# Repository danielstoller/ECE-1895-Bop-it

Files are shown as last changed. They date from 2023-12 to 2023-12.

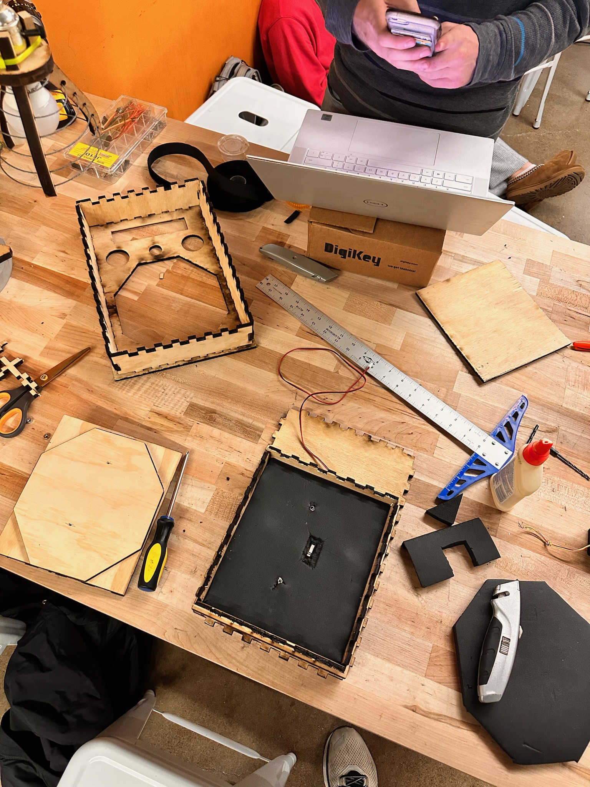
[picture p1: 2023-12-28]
Enclosure/pictures/enclosure_parts.JPG

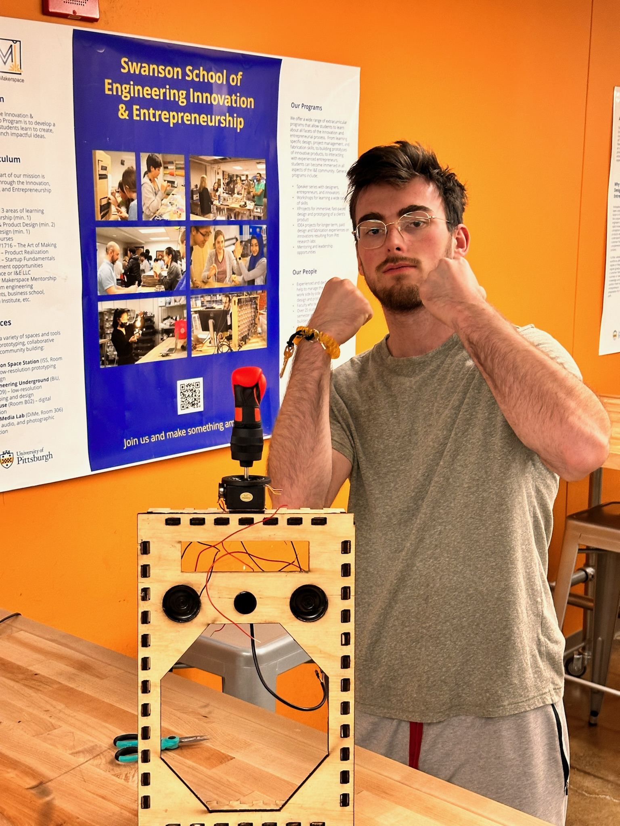
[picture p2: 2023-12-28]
Enclosure/pictures/IMG_3909.JPG

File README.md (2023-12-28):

# ECE 1895: Box It - The Boxing-Themed Twist on Bop It

## Objective

In our Junior Design class, my two teammates and I were tasked with creating a unique variation of the classic game Bop-It. The challenge included designing a game with three distinct actions, integrating both functional and hardware requirements. Box It offers a unique and physically engaging experience, turning a traditional punching bag into an interactive gaming device. Its combination of responsive sensors, intuitive actions, and immediate feedback makes it an exciting addition to both gaming and fitness routines. The primary objectives were to provide an engaging user experience, encourage physical activity, and incorporate responsive and intuitive decision making to help boxers sharpen their reaction time.

<br>

## Box It - The Implementation

Our twist on Bop It is called "Box It," a boxing-themed version of Bop It that is designed to be attached to a punching bag. The 13.5" x 8.5" laser printed enclosure houses various components including sensors, speakers, a display, a power source, and a PCB to connect them all together.

- **Actions:**
  1. **Punch It:**
     - Padded punching area with a limit switch detects hard punches.
  2. **Kick It:**
     - IR sensor on the side that detects kicks to the punching bag.
  3. **Dodge It:**
     - Proximity sensor in the center checks if the user successfully dodged.

- **Enclosure Features:**
  - LED matrix display with animations for visual cues.
  - Two speakers for audible commands.
  - Proximity sensor for responsive precise detection.
  - IR sensor for radial, inclusive detection
  - Limit switch for registering powerful punches.

- **Scoring and Feedback:**
  - Successful actions earn points, challenging users with decreasing time intervals.
  - Visual cues indicate success or failure, and the game ends after 99 successful attempts.

## Youtube Demonstration:
Watch the Video (https://youtu.be/TcJYKmGF-bU)

<br>

## Design Requirements

### Functional / Software Requirements

- **Power and Activation:**
  - The user can power the device on or off.
  - Upon activation, a button starts the game.

- **Game Commands:**
  - The device emits distinct, audible sounds specifying one of three commands.
  - The user must respond to the command with the corresponding action.

- **Scoring and Difficulty:**
  - Successful responses earn the user points.
  - After each successful attempt, the device issues a new command with a reduced time interval.
  - The game ends after 99 successful attempts, and the user is notified of their score.

- **Visual Cues:**
  - Visual cues indicate success or failure, providing immediate feedback to the user.

### Hardware Requirements

- **Power Source:**
  - The device is portable and battery-powered.

- **Enclosure:**
  - The device is enclosed with only inputs and outputs visible.
  - Compact and portable design for ease of use.

- **User Inputs:**
  - User-controlled inputs for powering the device and starting a new game.
  - Three tactile/sensory inputs for user responses.

- **Device Outputs:**
  - Three audible outputs for command specification.
  - Visual confirmation for successful and unsuccessful attempts.
  - Score notification at the end of each round.
 
<br>

## Responsibilities
- **Myself:**
    - Enclosure design, modeling, printing and assembly
    - LED Matrix animations
- **Tyler:**
    - PCB design and assembly
    - Component integration
- **Keegan:**
    - Game design and software

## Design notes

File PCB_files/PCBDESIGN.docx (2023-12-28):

Group Theta

Tyler Wiseman

Keegan Borig

Daniel Stoller

BopIt PCB

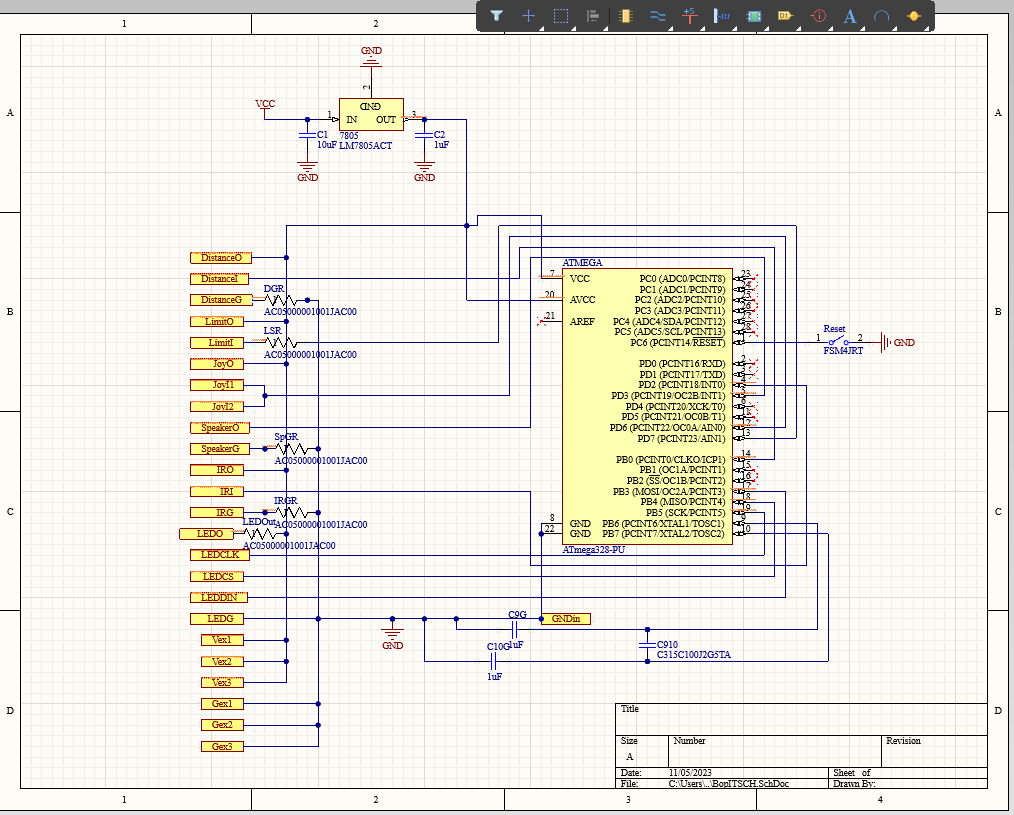
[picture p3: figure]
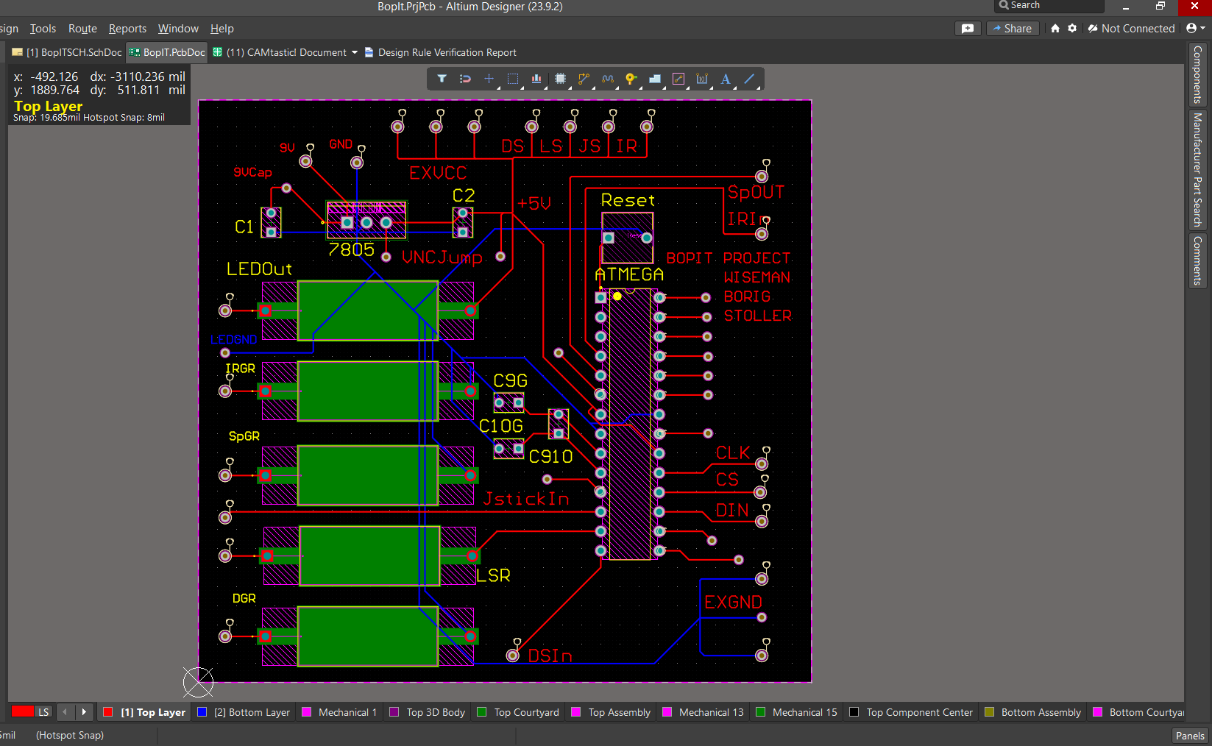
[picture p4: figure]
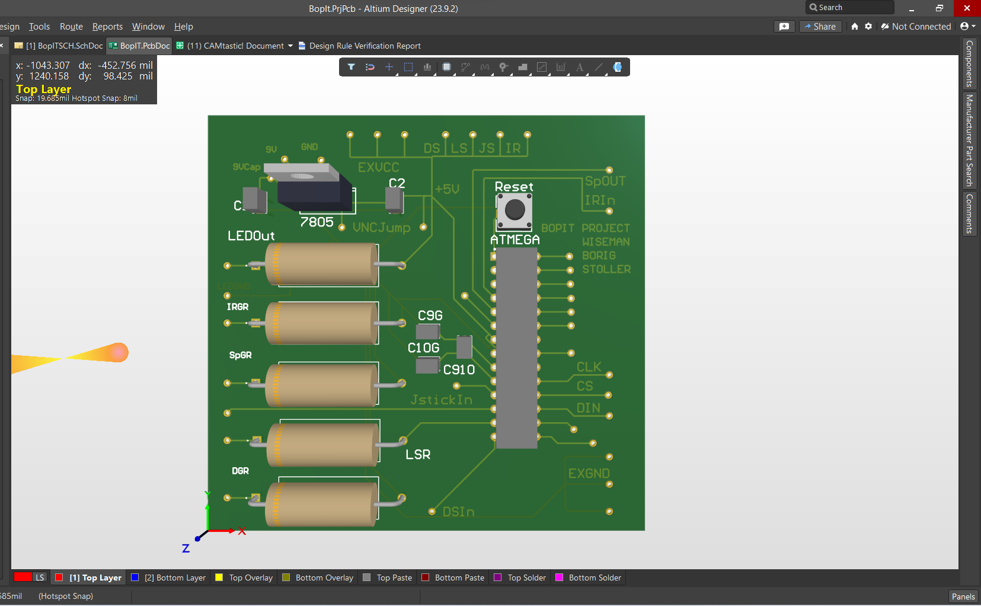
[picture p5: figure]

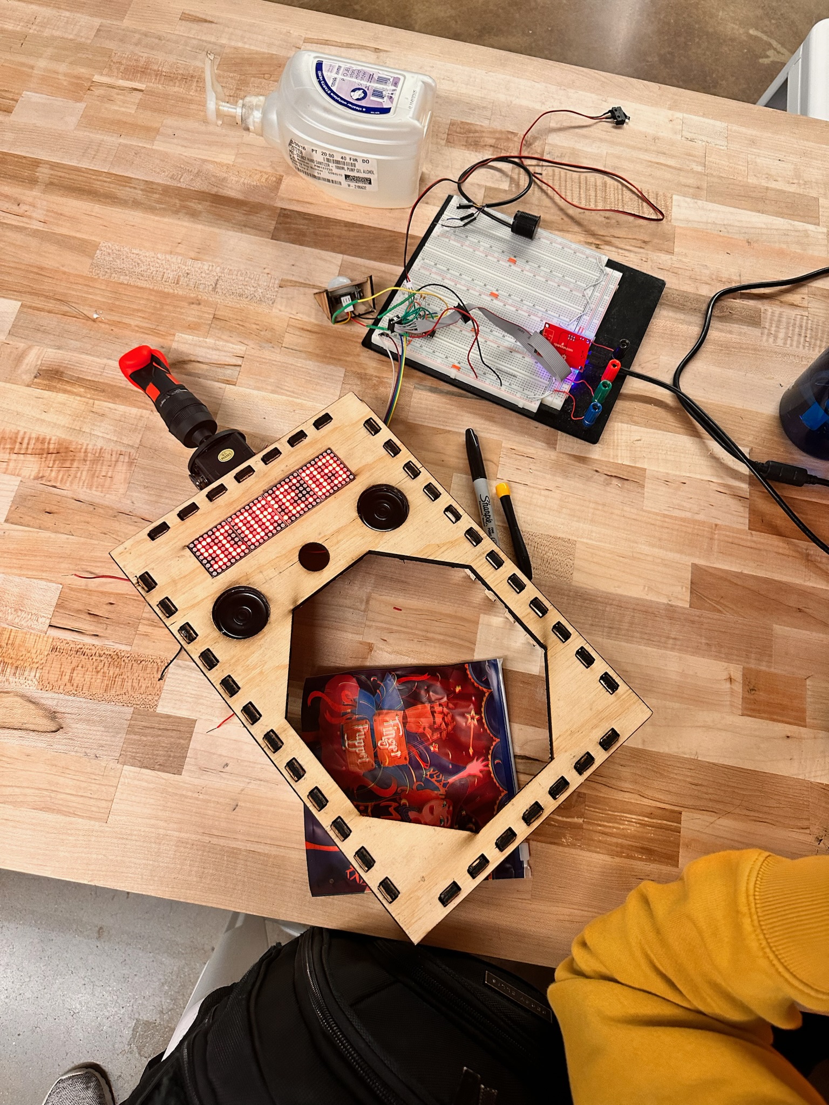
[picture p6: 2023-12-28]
Enclosure/pictures/enclosure_breadboard.JPG

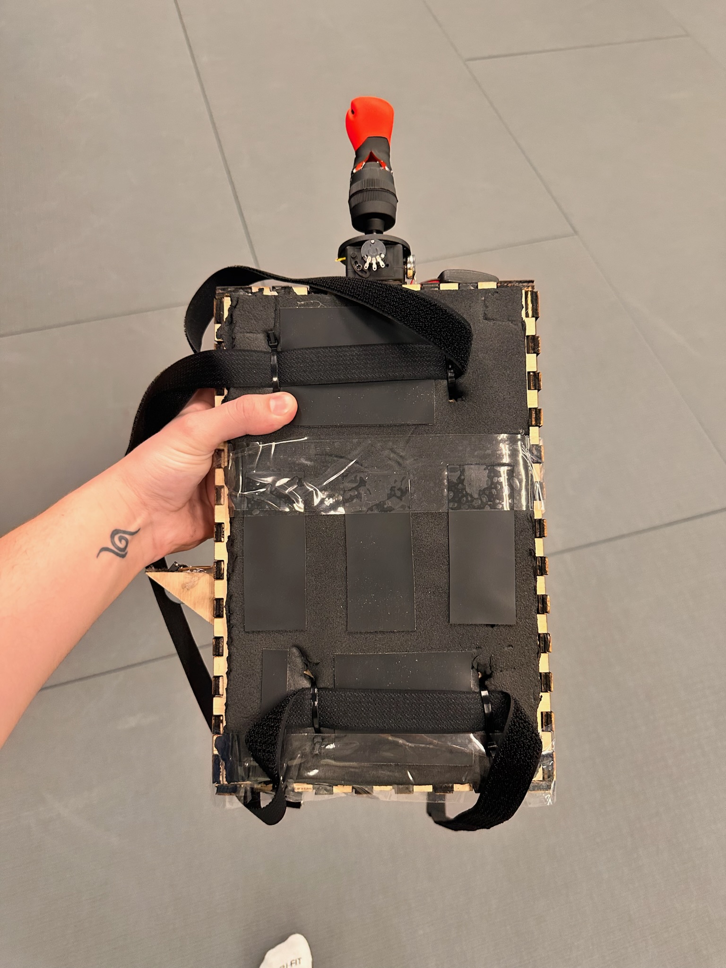
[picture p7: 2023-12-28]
Enclosure/pictures/enclosure_back.JPG

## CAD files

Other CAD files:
Enclosure/Enclosure Model v2.f3d

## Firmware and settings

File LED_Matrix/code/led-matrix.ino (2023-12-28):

#include <LedControl.h>

#include <LedControl.h>

#include <LedControl.h>

#include "LedControl.h"

//CLK is 13
//CS is 12
//DIN is 11

LedControl lc=LedControl(11,13,12,4);  // Pins: DIN,CLK,CS, # of Display connected

unsigned long delayTime=200;  // Delay between Frames


//lc.setRow(1, 0, B11100000);




void clear(){
  for(int i=0; i<4; i++)
    lc.clearDisplay(i);
}


void display(byte word[], int start, int size){
  for(int i=start; i<size; i++){
    if(i<0)
      lc.setColumn(3-i/8, i%8, word[i+start]);
  }
}


////////LOADING UP SCREEN//////////
byte leftPunch[] = 
{
  B01111100,
  B01000100,
  B01111110,
  B01111010,
  B01111110,
  B01111000,
  B01111000,
  B00111000
};



//Punches left glove across the screen
//i is the tip of the glove
//j is the bytes of the punching glove
void loadingScreen(){
  clear();
  for(int i=0; i<32; i++){
    for(int j=0; j<8; j++){
      if(j <= i)
        lc.setColumn(3-(i-j)/8, (i-j)%8, leftPunch[j]);  
    }
    delay(50);
  }
  
  /*
  delay(1000);
  clear();
  */
}


/////////START SCREEN/////////

byte start[] =
{
  B01110010,
  B01010010,
  B01011110,
  B00100000,
  B01111110,
  B00100000,
  B00000000,
  B00011110,

  B00010100,
  B00011110,
  B00000000,
  B00011110,
  B00010000,
  B00100000,
  B01111110,
  B00100000
};


//This puts the word start at the center of the screen
void showStart() {
  for (int i = 0; i < 16; i++)
  {
    lc.setColumn(2-i/8, i%8, start[i]);
  }
}


//Extended punch on both sides
void punchIn()
{
  for (int i = 0; i < 8; i++)
  {
    lc.setColumn(3, 7-i, leftPunch[i]);
    lc.setColumn(0, i, leftPunch[i]);
  }

  delay(2000);
}

//Retracted punch on both sides
void punchOut()
{
  lc.setColumn(3, 7, B00000000);
  lc.setColumn(0, 0, B00000000);
  for (int i = 0; i < 7; i++)
  {
    lc.setColumn(3, 6-i, leftPunch[i]);
    lc.setColumn(0, 1+i, leftPunch[i]);
  }
  delay(2000);
}

//This punches in and out once
void showPunch(){
  punchIn();
  punchOut();
}
  

//Displays start, then punches in and out once
//For overall code, startScreen(), while(joystick==0) showPunch();
void startScreen()
{
  clear();
  showStart();
  showPunch();
}


////////DODGE/////////

byte dodge[] = 
{
  //D, half of O
  B01111110,
  B01000010,
  B01000010,
  B00100100,
  B00011000,
  B00000000,
  B01111110,
  B01000010,

  //half of O, D
  B01000010,
  B01111110,
  B00000000,
  B01111110,
  B01000010,
  B01000010,
  B00100100,
  B00011000,

  //G, most of E
  B00000000,
  B01111110,
  B01000010,
  B01001010,
  B01001110,
  B00000000,
  B01111110,
  B01010010,

  //byte of E, slipstream
  B01010010,



  B00000000,
  B00010010,
  B00100100,
  B01001000,
  B01001000,
  B00100100,
  B00010010,

  //slipstream
  B00010010,
  B00100100,
  B01001000,
  B01001000,
  B00100100,
  B00010010,
  B00010010,
  B00100100,

  //slipstream
  B01001000,
  B01001000,
  B00100100,
  B00010010,
  B00010010,
  B00100100,
  B01001000,
  B01001000,
  B00100100,
  B00010010,

  //slipstream
  B00010010,
  B00100100,
  B01001000,
  B01001000,
  B00100100,
  B00010010,
  B00010010,
  B00100100
};



void showDodge(){
  //Will display 4 from the left and 5 from the right
  
  //**
  lc.setColumn(3, 0, B00000000);
  lc.setColumn(3, 1, B01000100);
  lc.setColumn(3, 2, B10101010);
  //**
  
  for(int i=4; i<30; i++){
    lc.setColumn(3-i/8, i%8, dodge[i-4]);
  }

  //**
  lc.setColumn(0, 5, B00000000);
  lc.setColumn(0, 6, B01000100);
  lc.setColumn(0, 7, B10101010);
  //**
}

//Arrows go in and out once
void dodgeArrows(){
  for(int i=1; i<3; i++){
    if(i%2){  //Extended
      lc.setColumn(3, 0, B01000010);
      lc.setColumn(3, 1, B10100101);
      lc.setColumn(3, 2, B00000000);
      lc.setColumn(0, 5, B01000010);
      lc.setColumn(0, 6, B10100101);
      lc.setColumn(0, 7, B00000000);
      delay(600);
    }
    else{   //Retracted
      lc.setColumn(3, 0, B00000000);
      lc.setColumn(3, 1, B01000010);
      lc.setColumn(3, 2, B10100101);
      lc.setColumn(0, 5, B00000000);
      lc.setColumn(0, 6, B01000010);
      lc.setColumn(0, 7, B10100101);
      delay(300);
    }
  }
}

//Will show the word dodge and arrows will go in and out n times
void dodgeScreen(int n){
  clear();
  showDodge();
  for(int i=0; i<n; i++){
    dodgeArrows();
  }
}


/////////PUNCH////////

byte punch[] = 
{
  //P and U
  B01111110,
  B01010000,
  B01110000,
  B00000000,
  B01111110,
  B00000010,
  B01111110,
  B00000000,

  //N and C
  B01111110,
  B00100000,
  B00010000,
  B01111110,
  B00000000,
  B01111110,
  B01000010,
  B01000010,

  //H
  B00000000,
  B01111110,
  B00010000,
  B01111110
};

void showPunch(){
  for(int i=6; i<26; i++){
    lc.setColumn(3-i/8, i%8, punch[i-6]);
  }
}

//The speed can be a number between 1 and 5
//1 is the fastest, 5 is the slowest
void explosion(int speed){
  for(int i=0; i<7; i++){
    if(i%7 == 0){  //Extended
      lc.setColumn(3, 0, B00000000);
      lc.setColumn(3, 1, B00000000);
      lc.setColumn(3, 2, B00000000);
      lc.setColumn(3, 3, B00000000);
      lc.setColumn(3, 4, B00011000);
      lc.setColumn(0, 3, B00011000);
      lc.setColumn(0, 4, B00000000);
      lc.setColumn(0, 5, B00000000);
      lc.setColumn(0, 6, B00000000);
      lc.setColumn(0, 7, B00000000);
      delay(speed*20);
    }
    else if(i%7 == 1){   //Retracted
      lc.setColumn(3, 3, B00011000);
      lc.setColumn(3, 4, B00100100);
      lc.setColumn(0, 4, B00011000);
      lc.setColumn(0, 3, B00100100);
      delay(speed*20);
    }
    else if(i%7 == 2){   //Retracted
      lc.setColumn(3, 2, B00011000);
      lc.setColumn(3, 3, B00100100);
      lc.setColumn(3, 4, B01000010);
      lc.setColumn(0, 5, B00011000);
      lc.setColumn(0, 4, B00100100);
      lc.setColumn(0, 3, B01000010);
      delay(speed*20);
    }
    else if(i%7 == 3){   //Retracted
      lc.setColumn(3, 1, B00011000);
      lc.setColumn(3, 2, B00100100);
      lc.setColumn(3, 3, B01000010);
      lc.setColumn(3, 4, B10000001);
      lc.setColumn(0, 6, B00011000);
      lc.setColumn(0, 5, B00100100);
      lc.setColumn(0, 4, B01000010);
      lc.setColumn(0, 3, B10000001);
      delay(speed*20);
    }
    else if(i%7 == 4){   //Retracted
      lc.setColumn(3, 0, B00011000);
      lc.setColumn(3, 1, B00100100);
      lc.setColumn(3, 2, B01000010);
      lc.setColumn(3, 3, B10000001);
      lc.setColumn(3, 4, B00000000);
      lc.setColumn(0, 7, B00011000);
      lc.setColumn(0, 6, B00100100);
      lc.setColumn(0, 5, B01000010);
      lc.setColumn(0, 4, B10000001);
      lc.setColumn(0, 3, B00000000);
      delay(speed*20);
    }
    else if(i%7 == 5){   //Retracted
      lc.setColumn(3, 0, B00100100);
      lc.setColumn(3, 1, B01000010);
      lc.setColumn(3, 2, B10000001);
      lc.setColumn(3, 3, B00000000);
      lc.setColumn(0, 7, B00100100);
      lc.setColumn(0, 6, B01000010);
      lc.setColumn(0, 5, B10000001);
      lc.setColumn(0, 4, B00000000);
      delay(speed*20);
    }
    else if(i%7 == 6){   //Retracted
      lc.setColumn(3, 0, B01000010);
      lc.setColumn(3, 1, B10000001);
      lc.setColumn(3, 2, B00000000);
      lc.setColumn(0, 7, B01000010);
      lc.setColumn(0, 6, B10000001);
      lc.setColumn(0, 5, B00000000);
      delay(speed*40);
    }
  }
}


void punchScreen(int n, int speed){
  clear();
  showPunch();
  for(int i=0; i<n; i++)
    explosion(speed);
}


////////KICK/////////

byte kick[] = 
{
  //K and I
  B01111110,
  B00010000,
  B00101000,
  B01000110,
  B00000000,
  B01000010,
  B01111110,
  B01000010,

  //C and most of K
  B00000000,
  B01111110,
  B01000010,
  B01000010,
  B00000000,
  B01111110,
  B00010000,
  B00101000,

  B01000110
};


void showKick(){
  for(int i=1; i<18; i++){
    lc.setColumn(3-i/8, i%8, kick[i-1]);
  }
}

byte man[] = 
{
  B11101001,
  B11111110,
  B11101001
};

byte flyingMan1[] = 
{
  B11101001,
  B11111110,
  B11101010,
  B00000100
};

byte flyingMan2[] = 
{
  B00000100,
  B11101001,
  B11111110,
  B11101010,
  B00000100,
  B00001000,
  B00010000
};


//Speed can be between 1 and 5 with 5 being the slowest
void flyingKick(int speed){
  
  //Standing man
  for(int i=19; i<22; i++){
    lc.setColumn(3-i/8, i%8, man[i-19]);
  }
  delay(120+30*speed);

  //Leg up
  //Clear previous line
  lc.setColumn(1, 3, B00000000);
  for(int i=20; i<24; i++){
    lc.setColumn(3-i/8, i%8, flyingMan1[i-20]);
  }

  delay(100+30*speed);

  //Flying kick
  for(int i=0; i<5; i++){
    //Clear previous line
    lc.setColumn(3-(i+20)/8, (i+20)%8, B00000000);
    for(int j=21; j<27; j++){
      lc.setColumn(3-(j+i)/8, (j+i)%8, flyingMan2[j-21]);
    }
    delay(60+30*speed);
  }

  //Leg up
  lc.setColumn(0, 1, B00000000);
  lc.setColumn(0, 2, B00000000);
  for(int i=27; i<30; i++){
    lc.setColumn(3-i/8, i%8, flyingMan1[i-27]);
  }
  lc.setColumn(0, 6, B00000000);
  delay(100+30*speed);

  //Standing man
  lc.setColumn(0, 2, B00000000);
  lc.setColumn(0, 3, B0000000);
  for(int i=28; i<31; i++){
    lc.setColumn(3-i/8, i%8, man[i-28]);
  }

  delay(170+30*speed);
  
  //Clear man
  for(int i=27; i<31; i++){
    lc.setColumn(3-i/8, i%8, B00000000);
  }
  

}

void kickScreen(){
  clear();
  showKick();
  flyingKick();
}


/////////SCORE////////

byte score[]{
  //S and C
  B00000000,
  B01110010,
  B01010010,
  B01011110,
  B00000000,
  B01111110,
  B01000010,
  B01000010,

  //O and most of R
  B00000000,
  B01111110,
  B01000010,
  B01111110,
  B00000000,
  B01111110,
  B01011000,
  B01010100,

  //little bit of R, E and :
  B01110010,
  B00000000,
  B01111110,
  B01010010,
  B01010010,
  B00000000,
  B01000010,
  B00000000
};

byte zero[]{
  B01111110,
  B01000010,
  B01111110
};

byte one[]{
  B00100010,
  B01111110,
  B00000010
};


byte two[]{
  B01011110,
  B01010010,
  B01110010
};


byte three[]{
  B01010010,
  B01010010,
  B01111110
};


byte four[]{
  B01110000,
  B00010000,
  B01111110
};


byte five[]{
  B01110010,
  B01010010,
  B01011110
};


byte six[]{
  B01111110,
  B00001010,
  B00001110
};


byte seven[]{
  B01000000,
  B01000000,
  B01111110
};


byte eight[]{
  B01111110,
  B01010010,
  B01111110
};


byte nine[]{
  B01110000,
  B01010000,
  B01111110
};


void showScore(){
  for(int i=0; i<24; i++){
    lc.setColumn(3-i/8, i%8, score[i]);
  }
}


void showTens(int num){
  if(num > 99)
    return;

  if(num/10 == 0){
    for(int i=0; i<3; i++)
      lc.setColumn(0, i, zero[i]);
  }
  else if(num/10 == 1){
    for(int i=0; i<3; i++)
      lc.setColumn(0, i, one[i]);
  }
  else if(num/10 == 2){
    for(int i=0; i<3; i++)
      lc.setColumn(0, i, two[i]);
  }
  else if(num/10 == 3){
    for(int i=0; i<3; i++)
      lc.setColumn(0, i, three[i]);
  }
  else if(num/10 == 4){
    for(int i=0; i<3; i++)
      lc.setColumn(0, i, four[i]);
  }
  else if(num/10 == 5){
    for(int i=0; i<3; i++)
      lc.setColumn(0, i, five[i]);
  }
  else if(num/10 == 6){
    for(int i=0; i<3; i++)
      lc.setColumn(0, i, six[i]);
  }
  else if(num/10 == 7){
    for(int i=0; i<3; i++)
      lc.setColumn(0, i, seven[i]);
  }
  else if(num/10 == 8){
    for(int i=0; i<3; i++)
      lc.setColumn(0, i, eight[i]);
  }
  else{
    for(int i=0; i<3; i++)
      lc.setColumn(0, i, nine[i]);
  }
}

void showOnes(int num){
  if(num > 99)
    return;

  if(num%10 == 0){
    for(int i=0; i<3; i++)
      lc.setColumn(0, i+4, zero[i]);
  }
  else if(num%10 == 1){
    for(int i=0; i<3; i++)
      lc.setColumn(0, i+4, one[i]);
  }
  else if(num%10 == 2){
    for(int i=0; i<3; i++)
      lc.setColumn(0, i+4, two[i]);
  }
  else if(num%10 == 3){
    for(int i=0; i<3; i++)
      lc.setColumn(0, i+4, three[i]);
  }
  else if(num%10 == 4){
    for(int i=0; i<3; i++)
      lc.setColumn(0, i+4, four[i]);
  }
  else if(num%10 == 5){
    for(int i=0; i<3; i++)
      lc.setColumn(0, i+4, five[i]);
  }
  else if(num%10 == 6){
    for(int i=0; i<3; i++)
      lc.setColumn(0, i+4, six[i]);
  }
  else if(num%10 == 7){
    for(int i=0; i<3; i++)
      lc.setColumn(0, i+4, seven[i]);
  }
  else if(num%10 == 8){
    for(int i=0; i<3; i++)
      lc.setColumn(0, i+4, eight[i]);
  }
  else{
    for(int i=0; i<3; i++)
      lc.setColumn(0, i+4, nine[i]);
  }
}

void scoreScreen(int score){
  clear();
  showScore();
  showTens(score);
  showOnes(score);
}


////LOSE SCREEN////

byte youLose[] =
{
  B01000000,
  B00100000,
  B00011110,
  B00100000,
  B01000000,
  B00111100,
  B01000010,
  B01000010,

  B00111100,
  B00000000,
  B01111110,
  B00000010,
  B01111110,
  B00000000,
  B00000000,
  B00000000,

  B01111110,
  B00000010,
  B00000010,
  B00000000,
  B00111100,
  B01000010,
  B01000010,
  B00111100,

  B00000000,
  B01110010,
  B01010010,
  B01011110,
  B00000000,
  B01111110,
  B01010010,
  B01000010,
};

byte pathetic[] =
{
  //P and A
  B01111110,
  B01010000,
  B01110000,
  B00000000,
  B01111110,
  B01001000,
  B01111110,
  B00000000,
  
  //T and H
  B01000000,
  B01111110,
  B01000000,
  B00000000,
  B01111110,
  B00010000,
  B01111110,
  B00000000,
  
  //E, T and part of I
  B01111110,
  B01010010,
  B00000000,
  B01000000,
  B01111110,
  B01000000,
  B00000000,
  B01000010,
  
  //Most of I, C, and period
  B01111110,
  B01000010,
  B00000000,
  B01111110,
  B01000010,
  B01000010,
  B00000000,
  B00000010,
};

byte laughable[] =
{
  //L, A, and part of U
  B01111110,
  B00000010,
  B00000000,
  B01111110,
  B01010000,
  B01111110,
  B00000000,
  B01111110,
  
  //Most of U, G, and part of H
  B00000010,
  B01111110,
  B00000000,
  B01111110,
  B01000010,
  B01001110,
  B00000000,
  B01111110,

  //Most of H, A, and part of B
  B00010000,
  B01111110,
  B00000000,
  B01111110,
  B01010000,
  B01111110,
  B00000000,
  B01111110,

  //Most of B, L, and E
  B01010010,
  B00101100,
  B00000000,
  B01111110,
  B00000010,
  B00000000,
  B01111110,
  B01010010
};

byte abysmal[] =
{
  //A and B
  B01111110,
  B01010000,
  B01111110,
  B00000000,
  B01111110,
  B01010010,
  B01010010,
  B00101100,
  
  //Y and part of S
  B00000000,
  B01000000,
  B00100000,
  B00011110,
  B00100000,
  B01000000,
  B00000000,
  B01110010,
  
  //Most of S and M
  B01010010,
  B01011110,
  B00000000,
  B01111110,
  B00100000,
  B00010000,
  B00100000,
  B01111110,
  
  //A and L
  B00000000,
  B01111110,
  B01010000,
  B01111110,
  B00000000,
  B01111110,
  B00000010,
  B00000010
};

void showBoo(){
  int randNum = random(0,3);
  for(int i=0; i<32; i++){
    if(randNum == 1)
      lc.setColumn(3-i/8, i%8, pathetic[i]);
    else if(randNum == 2)
      lc.setColumn(3-i/8, i%8, abysmal[i]);
    else
      lc.setColumn(3-i/8, i%8, laughable[i]);
  }
}

void showLose(){
  for(int i=0; i<32; i++){
    lc.setColumn(3-i/8, i%8, youLose[i]);
  }
}

void glitch(){
  for(int count = 0; count < 5; count++){
    for(int row=0; row<8; row++){
      for(int addr = 0; addr<4; addr++)
        for(int pixel=0; pixel<8; pixel++){
          int randNum = random(0,4);
          lc.setLed(addr, row, pixel, randNum);
        }
    }
  }
}


void loseScreen(){

  clear();

  //Transition Screen//
  glitch();
  
  showBoo();
  delay(1500);
  showLose();
  delay(1500);
  clear();
}



////////WIN////////


byte sublime[] = 
{
  //S and U
  B00000000,
  B01110010,
  B01010010,
  B01011110,
  B00000000,
  B01111110,
  B00000010,
  B01111110,
  
  //B and most of L
  B00000000,
  B01111110,
  B01010010,
  B01010010,
  B00101100,
  B00000000,
  B01111110,
  B00000010,
  
  //Part of L, I, and half of M
  B00000010,
  B00000000,
  B01000010,
  B01111110,
  B01000010,
  B00000000,
  B01111110,
  B00100000,
  
  //Half of M and E
  B00010000,
  B00100000,
  B01111110,
  B00000000,
  B01111110,
  B01010010,
  B01010010,
  B00000000
};

byte hooray[] =
{
  //H and O
  B00000000,
  B01111110,
  B00010000,
  B01111110,
  B00000000,
  B01111110,
  B01000010,
  B01111110,

  //O and most of R
  B00000000,
  B01111110,
  B01000010,
  B01111110,
  B00000000,
  B01111110,
  B01011000,
  B01010100,
  
  //Bit of R, A, and half of Y
  B01110010,
  B00000000,
  B01111110,
  B01010000,
  B01111110,
  B00000000,
  B01000000,
  B00100000,
  
  //Half of Y and !
  B00011110,
  B00100000,
  B01000000,
  B00000000,
  B00000000,
  B01111010,
  B00000000,
  B00000000,
};

byte cheeky[] =
{
  //C and H
  B00000000,
  B01111110,
  B01000010,
  B01000010,
  B00000000,
  B01111110,
  B00010000,
  B01111110,

  //Both E's
  B00000000,
  B01111110,
  B01010010,
  B01010010,
  B00000000,
  B01111110,
  B01010010,
  B01010010,
  
  //K and half of Y
  B00000000,
  B01111110,
  B00010000,
  B00101000,
  B01000110,
  B00000000,
  B01000000,
  B00100000,
  
  //Half of Y and !
  B00011110,
  B00100000,
  B01000000,
  B00000000,
  B00000000,
  B01111010,
  B00000000,
  B00000000,
};

byte blimey[] =
{
  //B and most of L
  B00000000,
  B01111110,
  B01010010,
  B01010010,
  B00101100,
  B00000000,
  B01111110,
  B00000010,

  //part of L, I, and half of M
  B00000010,
  B00000000,
  B01000010,
  B01111110,
  B01000010,
  B00000000,
  B01111110,
  B00100000,

  //Half of M and E
  B00010000,
  B00100000,
  B01111110,
  B00000000,
  B01111110,
  B01010010,
  B01010010,
  B00000000,
  
  //Y and !
  B01000000,
  B00100000,
  B00011110,
  B00100000,
  B01000000,
  B00000000,
  B01111010,
  B00000000,
};

byte youWin[] =
{
  //Y and part of O
  B00000000,
  B01000000,
  B00100000,
  B00011110,
  B00100000,
  B01000000,
  B00000000,
  B01111110,

  //Most of O and U
  B01000010,
  B01111110,
  B00000000,
  B01111110,
  B00000010,
  B01111110,
  B00000000,
  B00000000,
  
  //W and part of I
  B00000000,
  B01111110,
  B00000010,
  B00011110,
  B00000010,
  B01111110,
  B00000000,
  B01000010,
  
  //Most of I and N
  B01111110,
  B01000010,
  B00000000,
  B01111110,
  B00100000,
  B00010000,
  B01111110,
  B00000000
};

void showCongrats(){
  int randNum = random(0,4);
  for(int i=0; i<32; i++){
    if(randNum == 0)
      lc.setColumn(3-i/8, i%8, sublime[i]);
    else if(randNum == 1)
      lc.setColumn(3-i/8, i%8, hooray[i]);
    else if (randNum == 2)
      lc.setColumn(3-i/8, i%8, cheeky[i]);
    else
      lc.setColumn(3-i/8, i%8, blimey[i]);
  }
}

void showWin(){
  for(int i=0; i<32; i++){
    lc.setColumn(3-i/8, i%8, youWin[i]);
  }
}

void winScreen(){
  
  clear();
  //Transition screeen
  glitch();
  
  showCongrats();

  delay(1000);

  clear();
  showWin();

  delay(1000);

  clear();
}


void setup()
{
  lc.shutdown(0,false);  // Wake up displays
  lc.shutdown(1,false);
  lc.shutdown(2,false);
  lc.shutdown(3,false);
  lc.setIntensity(0,5);  // Set intensity levels
  lc.setIntensity(1,5);
  lc.setIntensity(2,5);
  lc.setIntensity(3,5);
  lc.clearDisplay(0);  // Clear Displays
  lc.clearDisplay(1);
  lc.clearDisplay(2);
  lc.clearDisplay(3);
}


void loop()
{
  //loadingScreen();
  //startScreen();
  //punchScreen();
  //kickScreen();
  //dodgeScreen();

  

  //int randNum = random(0,100);

  /*for(int i=0; i<10; i++){
    loseScreen();
    scoreScreen(i);
    delay(1000);
  }*/
  

  /*for(int i=0; i<10; i++){
    winScreen();
    scoreScreen(i);
    delay(1000);
  }*/
  


}

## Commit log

2023-12-28 Create PCB_files
2023-12-28 Update and rename led-matrix.ino to LED_Matrix/led-matrix.ino
2023-12-28 Update and rename LED_Matrix/led-matrix.ino to LED_Matrix/code/led-matrix.ino
